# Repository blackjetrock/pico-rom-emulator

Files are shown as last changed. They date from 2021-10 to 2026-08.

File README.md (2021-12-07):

# pico-rom-emulator
ROM Emulator using Pico

This is a ROM emulator using a Raspberry Pi Pico to do the emulation in firmware.
The emulator is a small program that presents data on 8 data lines depending on the state of 16 address lines.
As the emulation is done in firmware there is a limit to the speed of ROm that can be emulated.
This has been teste on a 900kHz 6303 system (Psion Organiser) and also a 2MHz 6502 system. It may be able to run faster
and with overclocking faster than the standard clock rate can handle. 
As emulation is in firmware you get an extra for free, namely an address tracing facility. It can be set to start on any address, all setup is done
using the code itself and the trace is accessed through a debugger, I use Eclipse.

The emulation currently runs on the second core of the RP2040, as I was having problems with the interrupts on core0 mucking up
the emulation, turning interrupts off was a problem as download didn't work well. Using core 1 seems to be a better solution. It may even be possible to 
run a USB serial monitor of some kind on core 0 while emulating. I haven't got round ot this yet.

There's a PCB in the repo too, which is a Pico and some level shifters to allow the emulator to run on a 5V system when the Pico is 3V3. The data direction
is under firmware control. I have been using the emulator configured with a hardware OE which menas the OE signal to the ROM goes to the CE of the level
shifters. Placing data on the bus is therefore under hardware control. The PCB can be configured in other ways but I've not tried that.

This is a work in progress, but I have used it to get traces for stuff I've been working on.

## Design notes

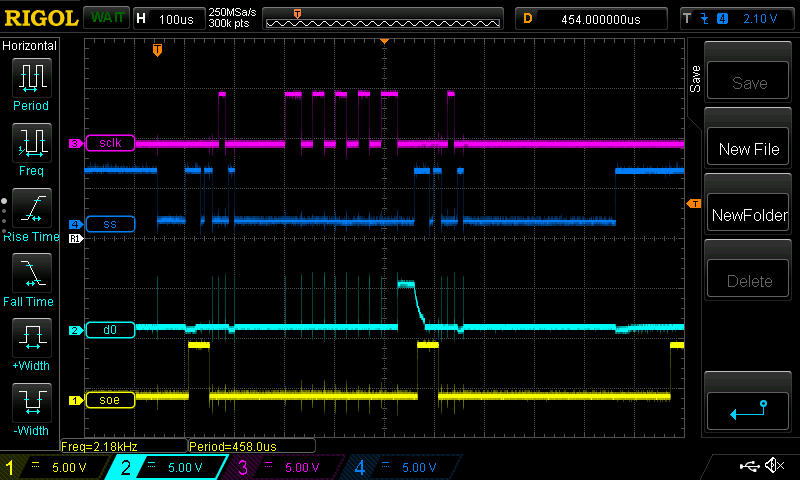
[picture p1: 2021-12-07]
code/pico-rom-em/scope_traces/rl_ep3.jpg

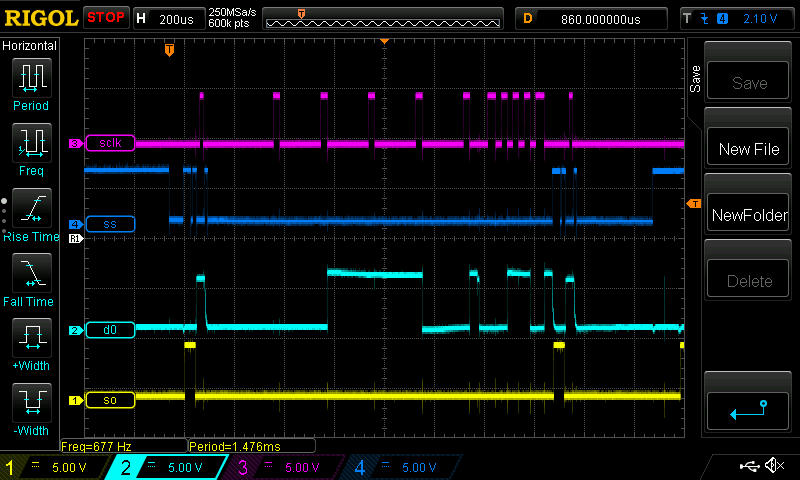
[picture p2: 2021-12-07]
code/scope_traces/rra2.jpg

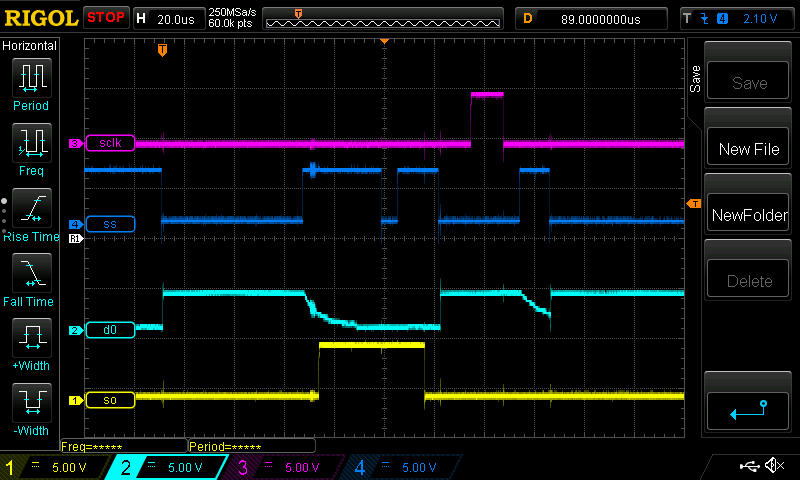
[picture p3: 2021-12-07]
code/scope_traces/g1.jpg

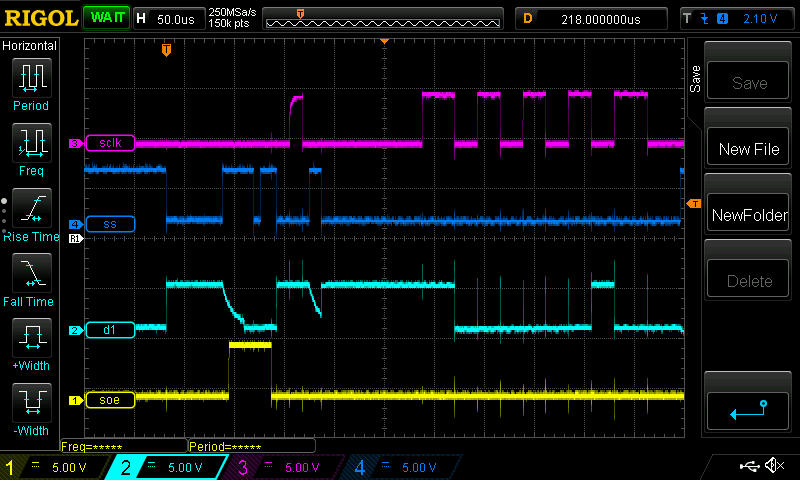
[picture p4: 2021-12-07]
code/scope_traces/rl_ep_d1_2.jpg

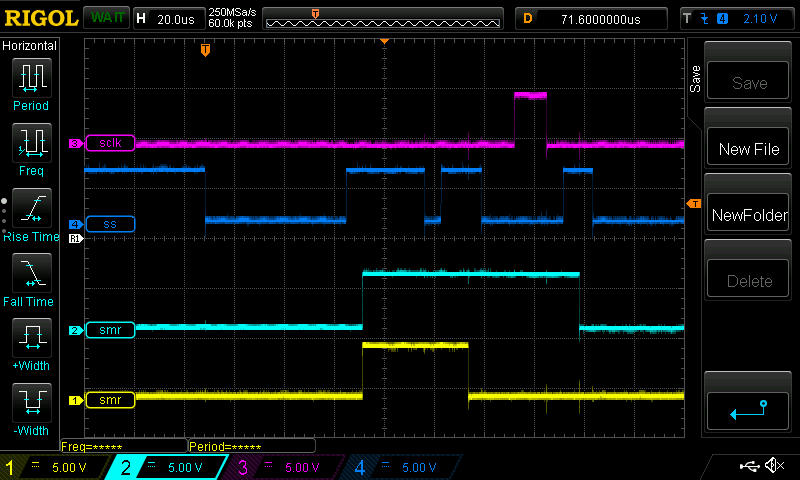
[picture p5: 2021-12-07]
code/pico-rom-em/scope_traces/NewFile10.jpg

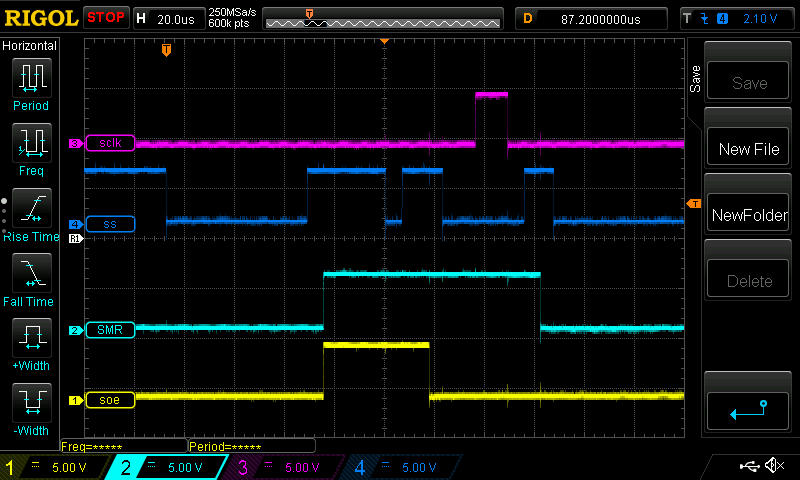
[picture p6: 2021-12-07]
code/scope_traces/RAMPAK2.jpg

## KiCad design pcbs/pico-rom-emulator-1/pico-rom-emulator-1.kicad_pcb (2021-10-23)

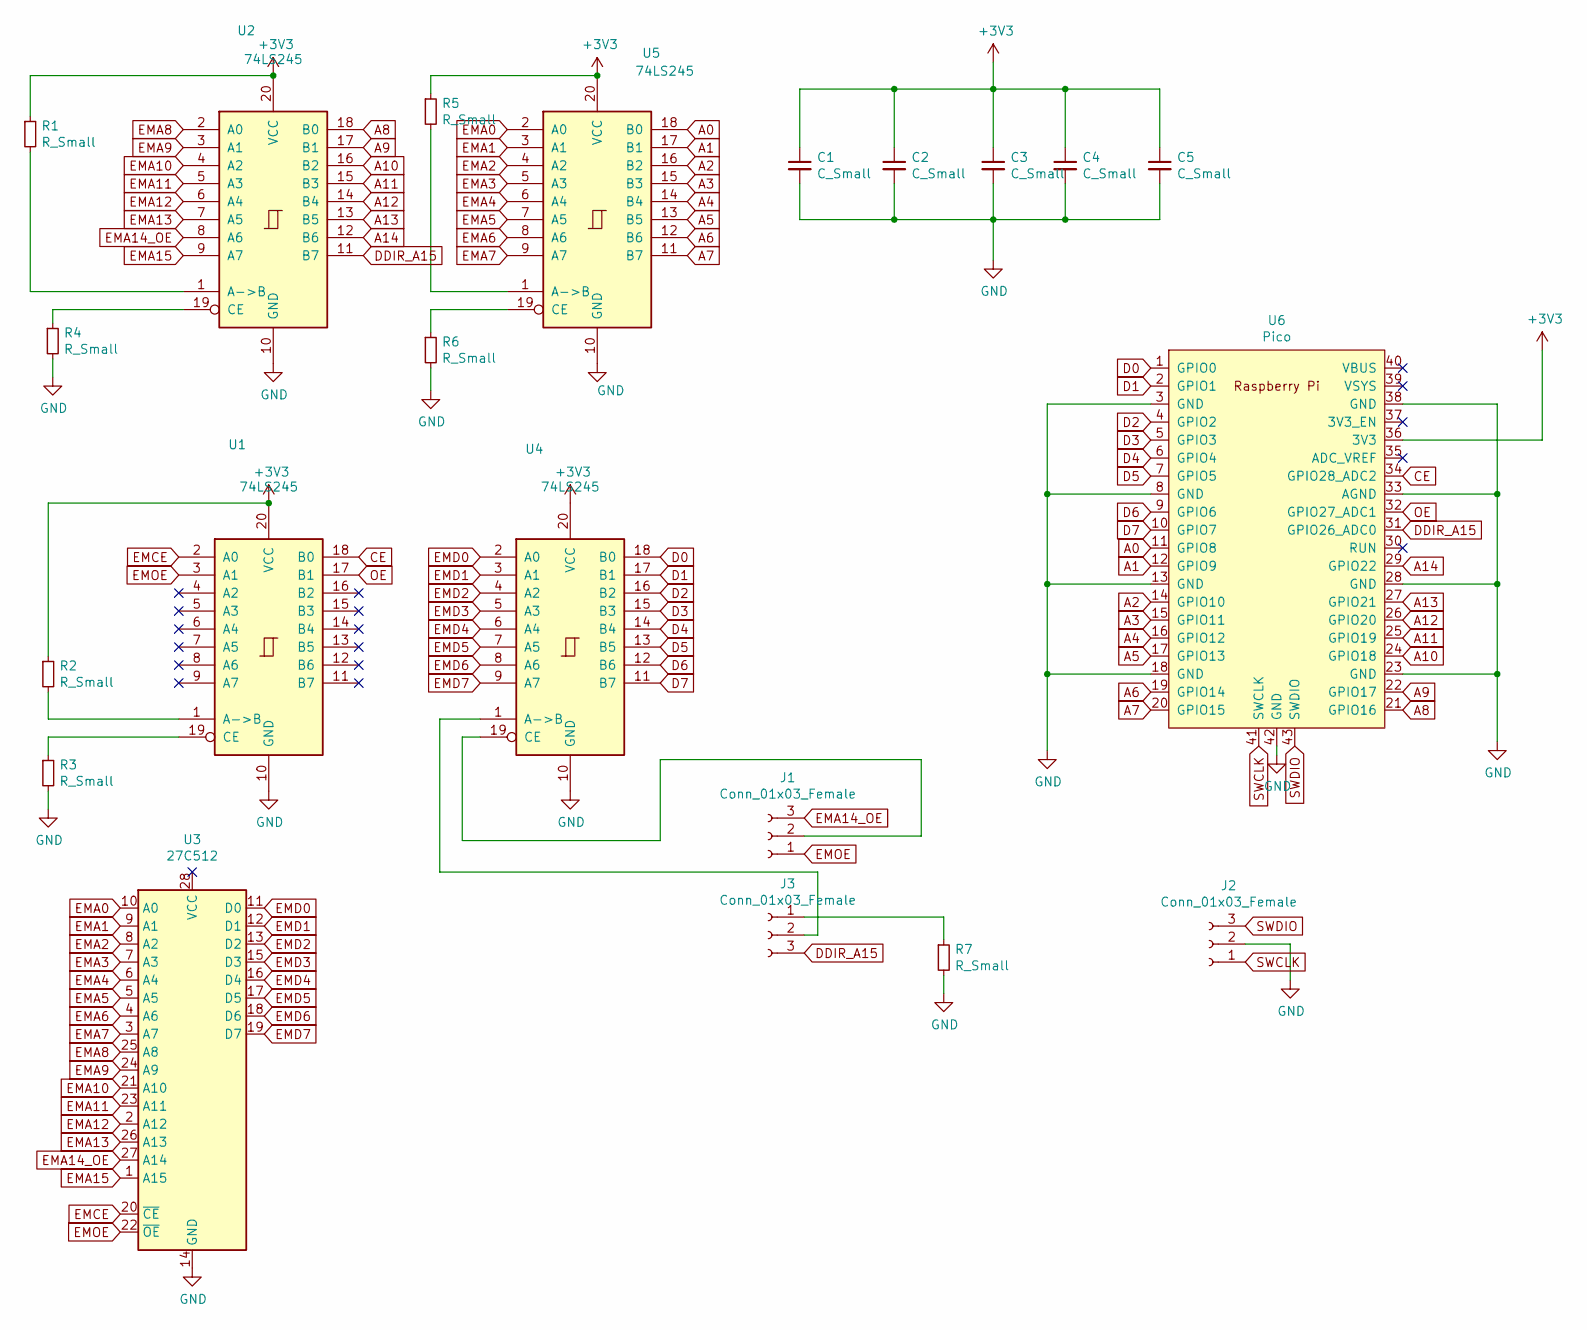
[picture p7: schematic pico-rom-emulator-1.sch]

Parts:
C1, C2, C3, C4, C5: C_Small; C_0805_2012Metric_Pad1.15x1.40mm_HandSolder
J1, J2, J3: Conn_01x03_Female; PinHeader_1x03_P2.54mm_Vertical
R1, R2, R3, R4, R5, R6, R7: R_Small; R_0805_2012Metric_Pad1.15x1.40mm_HandSolder
U1, U2, U4, U5: 74LS245; SOIC-20W_7.5x12.8mm_P1.27mm
U3: 27C512; DIP-28_W15.24mm
U6: Pico; RPi_Pico_SMD_TH

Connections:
+3V3: C1.1, C2.1, C3.1, C4.1, C5.1, R1.1, R2.1, R5.1, U1.20 (VCC), U2.20 (VCC), U4.20 (VCC), U5.20 (VCC), U6.36 (3V3)
A0: U5.18 (B0), U6.11 (GPIO8)
A1: U5.17 (B1), U6.12 (GPIO9)
A2: U5.16 (B2), U6.14 (GPIO10)
A3: U5.15 (B3), U6.15 (GPIO11)
A4: U5.14 (B4), U6.16 (GPIO12)
A5: U5.13 (B5), U6.17 (GPIO13)
A6: U5.12 (B6), U6.19 (GPIO14)
A7: U5.11 (B7), U6.20 (GPIO15)
A8: U2.18 (B0), U6.21 (GPIO16)
A9: U2.17 (B1), U6.22 (GPIO17)
A10: U2.16 (B2), U6.24 (GPIO18)
A11: U2.15 (B3), U6.25 (GPIO19)
A12: U2.14 (B4), U6.26 (GPIO20)
A13: U2.13 (B5), U6.27 (GPIO21)
A14: U2.12 (B6), U6.29 (GPIO22)
CE: U1.18 (B0), U6.34 (GPIO28_ADC2)
D0: U4.18 (B0), U6.1 (GPIO0)
D1: U4.17 (B1), U6.2 (GPIO1)
D2: U4.16 (B2), U6.4 (GPIO2)
D3: U4.15 (B3), U6.5 (GPIO3)
D4: U4.14 (B4), U6.6 (GPIO4)
D5: U4.13 (B5), U6.7 (GPIO5)
D6: U4.12 (B6), U6.9 (GPIO6)
D7: U4.11 (B7), U6.10 (GPIO7)
DDIR_A15: J3.3, U2.11 (B7), U6.31 (GPIO26_ADC0)
EMA0: U3.10 (A0), U5.2 (A0)
EMA1: U3.9 (A1), U5.3 (A1)
EMA2: U3.8 (A2), U5.4 (A2)
EMA3: U3.7 (A3), U5.5 (A3)
EMA4: U3.6 (A4), U5.6 (A4)
EMA5: U3.5 (A5), U5.7 (A5)
EMA6: U3.4 (A6), U5.8 (A6)
EMA7: U3.3 (A7), U5.9 (A7)
EMA8: U2.2 (A0), U3.25 (A8)
EMA9: U2.3 (A1), U3.24 (A9)
EMA10: U2.4 (A2), U3.21 (A10)
EMA11: U2.5 (A3), U3.23 (A11)
EMA12: U2.6 (A4), U3.2 (A12)
EMA13: U2.7 (A5), U3.26 (A13)
EMA14_OE: J1.3, U2.8 (A6), U3.27 (A14)
EMA15: U2.9 (A7), U3.1 (A15)
EMCE: U1.2 (A0), U3.20 (~CE)
EMD0: U3.11 (D0), U4.2 (A0)
EMD1: U3.12 (D1), U4.3 (A1)
EMD2: U3.13 (D2), U4.4 (A2)
EMD3: U3.15 (D3), U4.5 (A3)
EMD4: U3.16 (D4), U4.6 (A4)
EMD5: U3.17 (D5), U4.7 (A5)
EMD6: U3.18 (D6), U4.8 (A6)
EMD7: U3.19 (D7), U4.9 (A7)
EMOE: J1.1, U1.3 (A1), U3.22 (~OE)
GND: C1.2, C2.2, C3.2, C4.2, C5.2, J2.2, R3.2, R4.2, R6.2, R7.2, U1.10 (GND), U2.10 (GND), U3.14 (GND), U4.10 (GND), U5.10 (GND), U6.3 (GND), U6.8 (GND), U6.13 (GND), U6.18 (GND), U6.23 (GND), U6.28 (GND), U6.33 (AGND), U6.38 (GND), U6.42 (GND)
unnamed: J1.2, U4.19 (CE)
unnamed: J3.1, R7.1
unnamed: J3.2, U4.1 (A->B)
unnamed: R1.2, U2.1 (A->B)
unnamed: R2.2, U1.1 (A->B)
unnamed: R3.1, U1.19 (CE)
unnamed: R4.1, U2.19 (CE)
unnamed: R5.2, U5.1 (A->B)
unnamed: R6.1, U5.19 (CE)
OE: U1.17 (B1), U6.32 (GPIO27_ADC1)
SWCLK: J2.1, U6.41 (SWCLK)
SWDIO: J2.3, U6.43 (SWDIO)

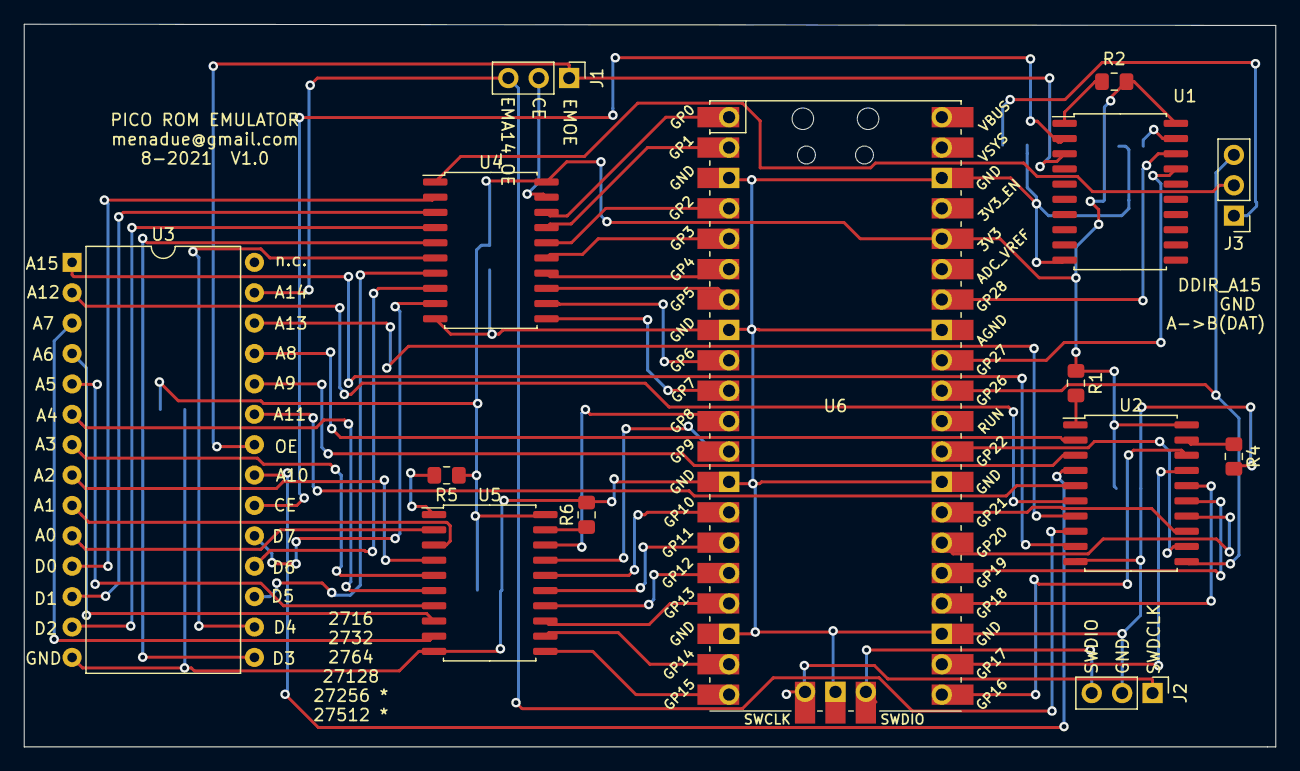
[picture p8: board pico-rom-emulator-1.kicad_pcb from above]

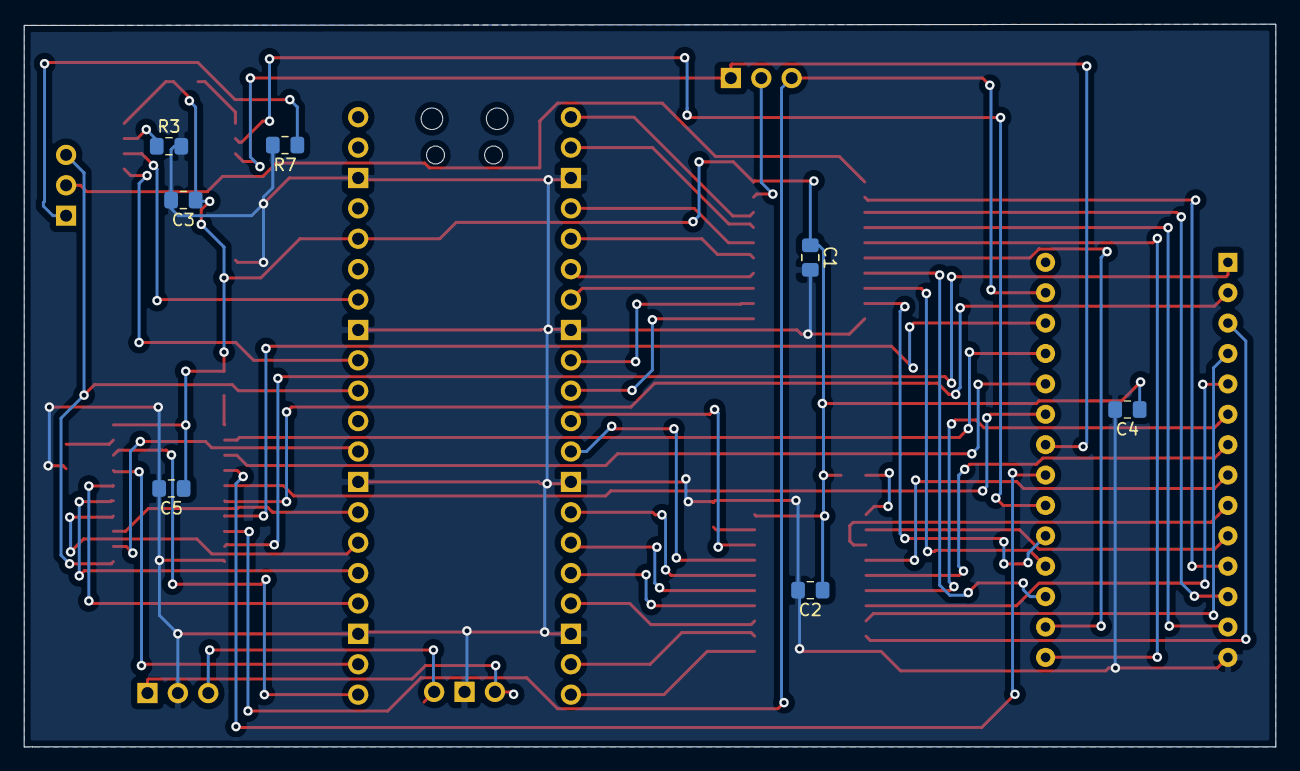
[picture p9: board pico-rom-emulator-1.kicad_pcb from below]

Board: 2 copper layers, 104.6 x 60.4 mm, 21 parts (7 on the bottom side), 65 nets.

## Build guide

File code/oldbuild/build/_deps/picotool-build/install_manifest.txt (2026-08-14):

/home/menadue/tree/github/pico-rom-emulator/code/build/_deps/picotool/picotool
/home/menadue/tree/github/pico-rom-emulator/code/build/_deps/picotool/picotoolTargets.cmake
/home/menadue/tree/github/pico-rom-emulator/code/build/_deps/picotool/picotoolTargets-release.cmake
/home/menadue/tree/github/pico-rom-emulator/code/build/_deps/picotool/picotoolConfig.cmake
/home/menadue/tree/github/pico-rom-emulator/code/build/_deps/picotool/picotoolConfigVersion.cmake

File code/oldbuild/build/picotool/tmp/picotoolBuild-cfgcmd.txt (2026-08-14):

cmd='/usr/bin/cmake;--no-warn-unused-cli;-DCMAKE_MAKE_PROGRAM:FILEPATH=/usr/bin/gmake;-DPICO_SDK_PATH:FILEPATH=/home/menadue/pico/pico-sdk;-DPICOTOOL_NO_LIBUSB=1;-DPICOTOOL_FLAT_INSTALL=1;-DCMAKE_INSTALL_PREFIX=/home/menadue/tree/github/pico-rom-emulator/code/build/_deps;-DCMAKE_RULE_MESSAGES=OFF;-DCMAKE_INSTALL_MESSAGE=NEVER;-GUnix Makefiles;-S;<SOURCE_DIR><SOURCE_SUBDIR>;-B;<BINARY_DIR>'

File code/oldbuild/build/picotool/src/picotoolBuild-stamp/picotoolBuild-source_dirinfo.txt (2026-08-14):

# This is a generated file and its contents are an internal implementation detail.
# The download step will be re-executed if anything in this file changes.
# No other meaning or use of this file is supported.

method=source_dir
command=
source_dir=/home/menadue/tree/github/pico-rom-emulator/code/build/_deps/picotool-src
work_dir=

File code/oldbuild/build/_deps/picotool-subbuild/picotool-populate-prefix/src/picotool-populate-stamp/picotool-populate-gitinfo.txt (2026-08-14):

# This is a generated file and its contents are an internal implementation detail.
# The download step will be re-executed if anything in this file changes.
# No other meaning or use of this file is supported.

method=git
command=/usr/bin/cmake;-DCMAKE_MESSAGE_LOG_LEVEL=VERBOSE;-P;/home/menadue/tree/github/pico-rom-emulator/code/build/_deps/picotool-subbuild/picotool-populate-prefix/tmp/picotool-populate-gitclone.cmake
source_dir=/home/menadue/tree/github/pico-rom-emulator/code/build/_deps/picotool-src
work_dir=/home/menadue/tree/github/pico-rom-emulator/code/build/_deps
repository=https://github.com/raspberrypi/picotool.git
remote=origin
init_submodules=TRUE
recurse_submodules=--recursive
submodules=
CMP0097=NEW

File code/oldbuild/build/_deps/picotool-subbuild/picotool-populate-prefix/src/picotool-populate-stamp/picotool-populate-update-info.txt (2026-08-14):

# This is a generated file and its contents are an internal implementation detail.
# The patch step will be re-executed if anything in this file changes.
# No other meaning or use of this file is supported.

command (connected)=/usr/bin/cmake;-Dcan_fetch=YES;-DCMAKE_MESSAGE_LOG_LEVEL=VERBOSE;-P;/home/menadue/tree/github/pico-rom-emulator/code/build/_deps/picotool-subbuild/picotool-populate-prefix/tmp/picotool-populate-gitupdate.cmake
command (disconnected)=/usr/bin/cmake;-Dcan_fetch=NO;-DCMAKE_MESSAGE_LOG_LEVEL=VERBOSE;-P;/home/menadue/tree/github/pico-rom-emulator/code/build/_deps/picotool-subbuild/picotool-populate-prefix/tmp/picotool-populate-gitupdate.cmake
work_dir=/home/menadue/tree/github/pico-rom-emulator/code/build/_deps/picotool-src

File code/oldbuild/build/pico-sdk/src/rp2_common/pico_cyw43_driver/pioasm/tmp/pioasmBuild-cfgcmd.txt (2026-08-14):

cmd='/usr/bin/cmake;--no-warn-unused-cli;-DCMAKE_MAKE_PROGRAM:FILEPATH=/usr/bin/gmake;-DPIOASM_FLAT_INSTALL=1;-DCMAKE_INSTALL_PREFIX=/home/menadue/tree/github/pico-rom-emulator/code/build/pioasm-install;-DCMAKE_RULE_MESSAGES=OFF;-DCMAKE_INSTALL_MESSAGE=NEVER;-GUnix Makefiles;-C<TMP_DIR>/pioasmBuild-cache-$<CONFIG>.cmake;-S;<SOURCE_DIR><SOURCE_SUBDIR>;-B;<BINARY_DIR>'

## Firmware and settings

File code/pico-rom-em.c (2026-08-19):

////////////////////////////////////////////////////////////////////////////////
//
// Pico ROM Emulator
//
////////////////////////////////////////////////////////////////////////////////


#include <ctype.h>
#include <stdio.h>
#include <string.h>
#include <stdlib.h>
#include "pico/stdlib.h"
//#include "hardware/i2c.h"
#include "hardware/pio.h"
#include "hardware/clocks.h"
#include "pico/multicore.h"
#include "pico/bootrom.h"

#if 0
#include "f_util.h"

#include "ff.h"
#include "ff_stdio.h"
#include "hw_config.h"
#include "my_debug.h"


#include "rtc.h"
#endif
#if 0
#include "sd_card.h"
#endif

typedef uint8_t BYTE;

// Use this if breakpoints don't work
#define DEBUG_STOP {volatile int x = 1; while(x) {} }

////////////////////////////////////////////////////////////////////////////////

void prompt(void);
void serial_help(void);

////////////////////////////////////////////////////////////////////////////////
//
// Tracing of processor accesses
//

#define TRACE_ON 0

// How many trace entries are displayed in a column
#define TRACE_B   32

// How many addresses are traced
#define TRACE_N   TRACE_B*4

volatile int trace_i = 0;
volatile int trace_running = 0;

volatile uint16_t trace_addr[TRACE_N];
volatile uint8_t trace_value[TRACE_N];
volatile char trace_type[TRACE_N];

////////////////////////////////////////////////////////////////////////////////


int parameter = 0;
int keypress = 0;

#define TEXT_PARAMETER_LEN 40
char text_parameter[TEXT_PARAMETER_LEN+1] = "";

//-----------------------------------------------------------------------------
//
// ROM Emulator Flags

// OE pin used to switch data direction
// If 0 then DDIR_A15 used, under processor conrol

#define USE_OE_FOR_DATA_DIRECTION 1

// The address lines we are looking at

// Do we run emulation on second core?
#define EMULATE_ON_CORE1   1

#define ROM_SIZE  2*1024
#define ADDRESS_MASK (ROM_SIZE - 1)


// Map from memory space to ROM address space
#define MAP_ROM(X) (X & ADDRESS_MASK)

volatile uint8_t rom_data[ROM_SIZE] =
  {
   // ASSEMBLER_EMBEDDED_CODE_START
0x4c,0x51,0xf9,0x4c,0xb2,0xf9,0x4c,0x9b,0xf9,0x4c,0x7d,0xfe,0xa9,0x0d,0x4c,0x79,
0xfe,0x4c,0xe9,0xfa,0x4c,0x0c,0xfb,0x4c,0x28,0xff,0x4c,0x0b,0xff,0x4c,0xfa,0xfd,
0xa2,0xff,0x9a,0x4c,0x37,0xfc,0x4c,0x16,0xfb,0x4c,0x23,0xfb,0x4c,0xdd,0xfe,0xf8,
0xfc,0x4c,0xc3,0xfe,0x4c,0x64,0xff,0xe0,0x03,0x01,0x00,0x00,0x00,0x40,0x24,0x00,
0x10,0x0a,0xa2,0x4f,0xb5,0x10,0x9d,0x00,0x01,0xca,0x10,0xf8,0xa9,0x00,0x85,0x00,
0xa9,0x8b,0x8d,0xd2,0xbf,0xa9,0xff,0x8d,0xd3,0xbf,0xa9,0x8b,0xcd,0xd2,0xbf,0xd0,
0x15,0xa9,0x93,0x8d,0xd3,0xbf,0xad,0xd1,0xbf,0x29,0x60,0xd0,0x09,0xa9,0x89,0x8d,
0xd2,0xbf,0xa9,0x21,0x85,0x00,0xa2,0xff,0x9a,0x4c,0x03,0xfc,0x85,0x02,0x8a,0x48,
0x98,0x48,0xad,0x2f,0xf8,0x48,0xad,0x30,0xf8,0x48,0xa6,0x02,0xa4,0x00,0x98,0x29,
0x04,0xd0,0x0a,0xe0,0x11,0xd0,0x18,0x98,0x09,0x04,0x85,0x00,0x60,0x98,0x29,0xfb,
0x85,0x00,0xe0,0x06,0xb0,0x09,0xbd,0x05,0xf9,0x48,0xbd,0x0b,0xf9,0x48,0x60,0xa5,
0x00,0x0a,0x0a,0xb0,0x0a,0x48,0x8a,0xc9,0x0a,0xf0,0x03,0x20,0x7d,0xfe,0x68,0xa6,
0x02,0xe0,0x7f,0xd0,0x04,0xa2,0x2f,0x86,0x02,0x0a,0x90,0x0d,0x48,0xe0,0x0d,0xd0,
0x04,0x29,0x10,0xd0,0x03,0x20,0x9b,0xf9,0x68,0x0a,0x90,0x0f,0x48,0xa6,0x02,0xe0,
0x0d,0xd0,0x04,0x29,0x20,0xf0,0x03,0x20,0xb2,0xf9,0x68,0x0a,0x90,0x03,0x20,0x02,
0xf9,0xa6,0x02,0xe0,0x0d,0xd0,0x05,0xa9,0x0a,0x20,0x7c,0xf8,0x60,0x68,0xa8,0x68,
0xaa,0x60,0x6c,0x11,0x00,0xf9,0xf9,0xf9,0xf9,0xf9,0xf9,0x8d,0x86,0x40,0x39,0x73,
0x7a,0x8d,0xf0,0xbf,0xc9,0x10,0xd0,0x06,0x20,0x34,0xf9,0x4c,0x2f,0xf9,0xc9,0x13,
0xd0,0x06,0x20,0x6e,0xf9,0x4c,0x2f,0xf9,0xc9,0x16,0xd0,0x07,0x20,0x81,0xf9,0xa9,
0x00,0x85,0x01,0x60,0xa5,0x00,0x29,0x10,0xf0,0x07,0xa5,0x00,0x29,0xef,0x85,0x00,
0x60,0xa9,0x00,0x8d,0xe3,0xbf,0xcd,0xe3,0xbf,0xd0,0x22,0xa5,0x00,0x09,0x10,0x85,
0x00,0xa9,0xff,0x8d,0xe3,0xbf,0xa9,0xfe,0x8d,0xe0,0xbf,0xa9,0x09,0x8d,0xe2,0xbf,
0xa9,0x0f,0x8d,0xe1,0xbf,0x20,0xdb,0xf9,0xa9,0xff,0x8d,0xe0,0xbf,0x60,0xa5,0x00,
0x29,0x40,0xf0,0x07,0xa5,0x00,0x29,0xbf,0x85,0x00,0x60,0xa5,0x00,0x09,0x40,0xd0,
0xf7,0xa5,0x00,0x29,0x20,0xf0,0x07,0xa5,0x00,0x29,0xdf,0x85,0x00,0x60,0xad,0xd2,
0xbf,0xc9,0xff,0xf0,0xf2,0xa5,0x00,0x09,0x20,0xd0,0xf0,0xa2,0x00,0xad,0xd1,0xbf,
0x29,0x10,0xd0,0x08,0x88,0xd0,0xfd,0xca,0xd0,0xf3,0xf0,0x3e,0xa5,0x02,0x8d,0xd0,
0xbf,0x60,0xad,0xe0,0xbf,0x29,0x04,0xf0,0x31,0xa2,0xff,0x98,0xa0,0x0f,0x88,0x10,
0xfd,0xa8,0x88,0xd0,0x03,0xca,0xf0,0x22,0xad,0xe0,0xbf,0x29,0x02,0xd0,0xec,0xad,
0xed,0xbf,0x29,0x02,0xf0,0xe5,0xa5,0x02,0x8d,0xe1,0xbf,0xa9,0x0d,0x8d,0xec,0xbf,
0xe9,0x01,0xd0,0xfc,0xa9,0x0f,0x8d,0xec,0xbf,0x60,0xa5,0x00,0x29,0x8f,0x85,0x00,
0xa2,0x0c,0xbd,0xfc,0xf9,0x20,0x79,0xfe,0xca,0x10,0xf7,0x60,0x0d,0x52,0x4f,0x52,
0x52,0x45,0x20,0x54,0x4e,0x49,0x52,0x50,0x0d,0x88,0x10,0x16,0xa5,0x0a,0x38,0xe9,
0x20,0x85,0x0a,0xa5,0x0b,0xe9,0x00,0x85,0x0b,0xa0,0x1f,0xc9,0x01,0xd0,0x03,0x20,
0x23,0xfa,0x60,0xa0,0x00,0xa9,0x20,0x99,0x00,0x02,0x99,0x00,0x03,0xc8,0xd0,0xf7,
0x98,0x85,0x0a,0xa9,0x02,0x85,0x0b,0x60,0xa2,0x00,0xbd,0x20,0x02,0x9d,0x00,0x02,
0xe8,0xd0,0xf7,0xbd,0x20,0x03,0x9d,0x00,0x03,0xe8,0xe0,0xe0,0xd0,0xf5,0x86,0x0a,
0xa9,0x03,0x85,0x0b,0xa9,0x20,0xa8,0x88,0x91,0x0a,0xd0,0xfb,0x60,0xa0,0x00,0xbd,
0x6d,0xfa,0xd0,0x01,0x60,0xd1,0x0a,0xd0,0xfb,0xe8,0xc8,0xd0,0xf2,0x42,0x41,0x53,
0x00,0x57,0x41,0x52,0x00,0xa2,0x00,0x20,0x5d,0xfa,0xd0,0x08,0x06,0x00,0x38,0x66,
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

// ASSEMBLER_EMBEDDED_CODE_END
  };

//------------------------------------------------------------------------------

const int D0_PIN = 0;
const int D1_PIN = 1;
const int D2_PIN = 2;
const int D3_PIN = 3;
const int D4_PIN = 4;
const int D5_PIN = 5;
const int D6_PIN = 6;
const int D7_PIN = 7;

//
// The address lines (always inputs)
//
const int  A0_PIN  =  8;
const int  A1_PIN  =  9;
const int  A2_PIN  = 10;
const int  A3_PIN  = 11;
const int  A4_PIN  = 12;
const int  A5_PIN  = 13;
const int  A6_PIN  = 14;
const int  A7_PIN  = 15;
const int  A8_PIN  = 16;
const int  A9_PIN  = 17;
const int  A10_PIN = 18;
const int  A11_PIN = 19;
const int  A12_PIN = 20;
const int  A13_PIN = 21;
const int  A14_PIN = 22;
const int  DDIR_A15_PIN = 26;

const int OE_PIN = 27;
const int CE_PIN = 28;

// Arrays for setting GPIOs up
#define NUM_ADDR 16
#define NUM_DATA 8

#define CE_OE_MASK ((1 << CE_PIN) | (1 << OE_PIN))

const int address_pins[NUM_ADDR] =
  {
   A0_PIN,
   A1_PIN,
   A2_PIN,
   A3_PIN,
   A4_PIN,
   A5_PIN,
   A6_PIN,
   A7_PIN,
   A8_PIN,
   A9_PIN,
   A10_PIN,
   A11_PIN,
   A12_PIN,
   A13_PIN,
   A14_PIN,
   DDIR_A15_PIN,
  };

const int data_pins[NUM_DATA] =
  {
   D0_PIN,
   D1_PIN,
   D2_PIN,
   D3_PIN,
   D4_PIN,
   D5_PIN,
   D6_PIN,
   D7_PIN,
  };

////////////////////////////////////////////////////////////////////////////////

//-----------------------------------------------------------------------------
//
// Put a value on the data bus

inline void set_data(BYTE data)
{
  int states;
  int dat = data & 0xff;
  
  // Direct register access to make things faster
  sio_hw->gpio_set = (  dat  << 0);
  sio_hw->gpio_clr = ((dat ^ 0xFF) << 0);
}



////////////////////////////////////////////////////////////////////////////////
//
// Set things up then sit in a loop waiting for the emulated devcie to
// be selected
//
////////////////////////////////////////////////////////////////////////////////

#define MAX_ADDR_TRACE 1024*64
int trace_on = 0;
volatile int addr_trace_index = 0;
volatile uint16_t addr_trace[MAX_ADDR_TRACE];
volatile unsigned int number_ce_assert = 0;

void rom_emulate(void)
{

  irq_set_mask_enabled( 0xFFFFFFFF, false );

  while(1)
    {
      uint32_t gpio_states;
      BYTE db;
      unsigned int addr;
      unsigned int last_addr;

      // Get off bus
      gpio_put(DDIR_A15_PIN, 1);
      
      // read GPIOs
      gpio_states = sio_hw->gpio_in;
      
      // We look for CE and OE being low
      if( (gpio_states & CE_OE_MASK) != 0 )
      	{
          // CE high, we are not selected

        }
      else
      	{
          // CE and OE low, we are selected
          // Drive bus
          gpio_put(DDIR_A15_PIN, 0);
                
          // ROM emulation so always a read of us
          // get address
          addr = (gpio_states >> 8) & ADDRESS_MASK;
	  
          // Get data and present it on bus
          set_data(rom_data[addr]);

          //          printf("\nA");
          //set_data(0xF8);
	  
#if TRACE_ON
          if( trace_running )
            {
              trace_addr[trace_i] = addr;
              trace_value[trace_i] = rom_data[addr];
              trace_type[trace_i++] = 'R';
              if( trace_i == TRACE_N )
                {
                  trace_running = 0;
                }
            }
#endif

          last_addr = addr;
          
          number_ce_assert++;
#if 1
          // Wait for CE or OE to be de-asserted
          while(1)
            {
              gpio_states = sio_hw->gpio_in;
	      
              // We look for CE and OE to be non zero
              if( (gpio_states & CE_OE_MASK) != 0 )
                {
                  // get off bus quickly
                  gpio_put(DDIR_A15_PIN, 1);
                  
                  //                  printf("\nD");
                  // CE or OE high, we are not selected
#if TRACE_ON
                  if( trace_running && (last_addr != addr)  )
                    {
                      trace_addr[trace_i] = addr;
                      trace_value[trace_i] = rom_data[addr];
                      trace_type[trace_i++] = 'X';
                      if( trace_i == TRACE_N )
                        {
                          trace_running = 0;
                        }
                    }
#endif
                  break;
                }

              // CE and OE low, we are selected
              // ROM emulation so always a read of us
              // get address
              addr = (gpio_states >> 8) & ADDRESS_MASK;
              
              // Get data and present it on bus
              set_data(rom_data[addr]);
              
#if TRACE_ON
              if( trace_running && (last_addr != addr)  )
                {
                  trace_addr[trace_i] = addr;
                  trace_value[trace_i] = rom_data[addr];
                  trace_type[trace_i++] = 'L';
                  if( trace_i == TRACE_N )
                    {
                      trace_running = 0;
                    }
                }
#endif
              last_addr = addr;
            }
#endif
        }
    }
}

////////////////////////////////////////////////////////////////////////////////
//
// trace what the processor is doing

void cli_trace_addresses(void)
{
  trace_i = 0;
  trace_running = 1;
}

void cli_dump_trace(void)
{
  printf("\nTrace\n");
  printf("\nTrace index;%d Trace running:%d\n", trace_i, trace_running);
  
  for(int i = 0; i<TRACE_B; i++)
    {
      printf("\n");
      for(int b = 0; b< TRACE_N/TRACE_B; b++)
        {
          int bi = i+TRACE_B*b;
          printf("%02X: %04X %c %02X   ", bi, trace_addr[bi], trace_type[bi], trace_value[bi]);
        }
    }
  printf("\n");
}


////////////////////////////////////////////////////////////////////////////////

void cli_boot_mass(void)
{
  reset_usb_boot(0,0);
}

void cli_information(void)
{
  printf("\nInformation");
}

////////////////////////////////////////////////////////////////////////////////
//
//
// We allow digits to enter a new value for the parameter

void cli_enter_parameter()
{
  int  key;
  int done = 0;

  printf("\nEnter parameter: (ESC or <RETURN> to exit)");
  
  parameter = 0;
  
  while(!done)
    {
      if( ((key = getchar_timeout_us(1000)) != PICO_ERROR_TIMEOUT))
	{
#if PAR_TYPE_DEC
	  switch(key)
	    {
	    case '0':
	    case '1':
	    case '2':
	    case '3':
	    case '4':
	    case '5':
	    case '6':
	    case '7':
	    case '8':
	    case '9':
	      parameter *= 10;
	      parameter += (key - '0');
	      prompt();
	      break;

	    case 27:
	    case 13:
	    case 10:
	      done = 1;
	      break;
	      
	    default:
	      break;
	    }
#else
	  switch(key)
	    {
	    case '0':
	    case '1':
	    case '2':
	    case '3':
	    case '4':
	    case '5':
	    case '6':
	    case '7':
	    case '8':
	    case '9':
	      parameter *= 16;
	      parameter += (key - '0');
	      prompt();
	      break;
              
	    case 'a':
	    case 'b':
	    case 'c':
	    case 'd':
	    case 'e':
	    case 'f':
	      parameter *= 16;
	      parameter += (key - 'a'+10);
	      prompt();
              break;
              
	    case 27:
	    case 13:
	    case 10:
	      done = 1;
	      break;
	      
	    default:
	      break;
	    }
#endif
	}
      else
	{
	  // I have found that I need to send something if the serial USB times out
	  // otherwise I get lockups on the serial communications.
	  // So, if we get a timeout we send a space and backspace it. And
	  // flush the stdio, but that didn't fix the problem but seems like a good idea.
	  stdio_flush();
	  //printf(" \b");
	}
    }
}

////////////////////////////////////////////////////////////////////////////////

#define BYTE_WIDTH 16

void cli_dump_ram(void)
{
  char ascii[BYTE_WIDTH*3+5];
  char ascii_byte[5];

  // Bound the address to 64K

  parameter %= 64*1024;
  
  // Display memory from address
  printf("\n");

  ascii[0] = '\0';
  
  for(unsigned int z = parameter; z<parameter+512; z++)
    {
      int byte = 0;
      
      if( (z % BYTE_WIDTH) == 0)
	{
	  printf("  %s", ascii);
	  ascii[0] = '\0';
	  printf("\n%08X: ", z);
	}

      byte = rom_data[z];

      printf(" %02X", byte);
      
      if( isprint(byte) )
	{
	  sprintf(ascii_byte, "%c", byte);
	}
      else
	{
	  sprintf(ascii_byte, ".");
	}
      
      strcat(ascii, ascii_byte);
    }
  
  printf("\n");

  parameter += 512;
}

//------------------------------------------------------------------------------

void cli_dump_ram2(void)
{
  for(int a=parameter; a<parameter+256; a++)
    {
      if( (a % 16) == 0 )
        {
          printf("\n%04X: ", a);
        }
      else
        {
          if( (a % 8) == 0 )
            {
              printf(" ");
            }
        }
      
      printf(" %02X", rom_data[a]);
    }

  printf("\n");
  
}
////////////////////////////////////////////////////////////////////////////////

void prompt(void)
{
  printf("\n\n(Text Parameter:'%s'", text_parameter);
#if PAR_TYPE_DEC
  printf("\n(Parameter %d >", parameter);
#else
  printf("\n(Parameter 0x%04X >", parameter);
#endif
}

////////////////////////////////////////////////////////////////////////////////

void cli_digit(void)
{
  printf("\n%d", keypress);
}

////////////////////////////////////////////////////////////////////////////////

// Serial loop command structure

typedef void (*SERIAL_FPTR)(void);

typedef struct
{
  char key;
  char *desc;
  SERIAL_FPTR fn;
} SERIAL_COMMAND;

SERIAL_COMMAND serial_cmds[] =
  {
    {
      '?',
      "Serial command help",
      serial_help,
    },
    {
      '!',
      "Boot to mass storage",
      cli_boot_mass,
    },
    {
      'i',
      "Information",
      cli_information,
    },
    {
      't',
      "Trace",
      cli_trace_addresses,
    },
    {
      'u',
      "Dump trace",
      cli_dump_trace,
    },
    {
      'a',
      "Dump RAM",
      cli_dump_ram,
    },
    {
      'z',
      "Enter parameter value",
      cli_enter_parameter,
    },
    {
      '0',
      "*Digit",
      cli_digit,
    },
    {
      '1',
      "*Digit",
      cli_digit,
    },
    {
      '2',
      "*Digit",
      cli_digit,
    },
    {
      '3',
      "*Digit",
      cli_digit,
    },
    {
      '4',
      "*Digit",
      cli_digit,
    },
    {
      '5',
      "*Digit",
      cli_digit,
    },
    {
      '6',
      "*Digit",
      cli_digit,
    },
    {
      '7',
      "*Digit",
      cli_digit,
    },
    {
      '8',
      "*Digit",
      cli_digit,
    },
    {
      '9',
      "*Digit",
      cli_digit,
    },
  };


////////////////////////////////////////////////////////////////////////////////
//
// Serial CLI Handling
//
////////////////////////////////////////////////////////////////////////////////

int pcount = 0;
int periodic_read = 0;

void serial_loop()
{
  int  key;
  
  if( ((key = getchar_timeout_us(1000)) != PICO_ERROR_TIMEOUT))
    {
      for(int i=0; i<sizeof(serial_cmds)/sizeof(SERIAL_COMMAND);i++)
	{
	  if( serial_cmds[i].key == key )
	    {
#if DEBUG_SERIAL
	      printf("\nKey:%d (0x%02X)", key, key);
#endif
	      keypress = key;
	      (*serial_cmds[i].fn)();
	      prompt();
	      break;
	    }
	}
    }
}

void serial_help(void)
{
  printf("\n");
  
  for(int i=0; i<sizeof(serial_cmds)/sizeof(SERIAL_COMMAND);i++)
    {
      if( *(serial_cmds[i].desc) != '*' )
	{
	  printf("\n%c:   %s", serial_cmds[i].key, serial_cmds[i].desc);
	}
    }
  printf("\n0-9: Enter parameter digit");
}


int main()
{

  ////////////////////////////////////////////////////////////////////////////////
  //
  // Overclock as needed
  //
  ////////////////////////////////////////////////////////////////////////////////
  
  //#define OVERCLOCK 135000
  //#define OVERCLOCK 200000
#define OVERCLOCK 270000
  //#define OVERCLOCK 360000
  
#if OVERCLOCK > 270000
  /* Above this speed needs increased voltage */
  vreg_set_voltage(VREG_VOLTAGE_1_20);
  sleep_ms(1000);
#endif
  
  /* Overclock */
  set_sys_clock_khz( OVERCLOCK, 1 );

  //DEBUG_STOP;
  
  char line[80];

  stdio_init_all();

  printf("\nPico ROM Emulator\n");
  
#if TEST_STDIO
  {
  int count;
  while (true)
    {
      count++;
      
      if( (count % 1000000) == 0 )
	{
	  sprintf(line, "\nRP2040: %d", count);
	  printf(line);
	}
    }
  }
#endif

  printf("\nSetting GPIOs...");

  for (int i=0; i<NUM_ADDR; i++)
    {
      // Set up directions for the control lines
      gpio_init(address_pins[i]);
      gpio_set_dir(address_pins[i], GPIO_IN);
    }

  for (int i=0; i<NUM_DATA; i++)
    {
      // Set up directions for the control lines
      gpio_init(data_pins[i]);
      gpio_set_dir(data_pins[i], GPIO_OUT);
    }

  gpio_init(OE_PIN);
  gpio_set_dir(OE_PIN, GPIO_IN);
  gpio_init(CE_PIN);
  gpio_set_dir(CE_PIN, GPIO_IN);

  // DEBUG: Use DDIR_A15 as status line
  gpio_init(DDIR_A15_PIN);
  gpio_set_dir(DDIR_A15_PIN, GPIO_OUT);

  int ce = 0;

#if 0
  while(1)
    {
      ce = gpio_get(CE_PIN);
      gpio_put(DDIR_A15_PIN, ce);
    }
#endif

#if 0
  while(1)
    {
      uint32_t gpio_states;
      gpio_states = sio_hw->gpio_in;
      if( gpio_states & (1 << CE_PIN))
	{
	  gpio_put(DDIR_A15_PIN, 1);
	}
      else
	{
	  gpio_put(DDIR_A15_PIN, 0);
	}
    }
#endif

#if 0
  gpio_init(DDIR_A15_PIN);
  gpio_set_dir(DDIR_A15_PIN, GPIO_OUT);

  while(1)
    {
      printf("\nONE");
      gpio_put(DDIR_A15_PIN, 1);
      printf("\nZero");
      gpio_put(DDIR_A15_PIN, 0);
    }
#endif

  
  //set_data_outputs();
#if 0
#if !USE_OE_FOR_DATA_DIRECTION


  // LS_DIR is an output
  gpio_set_dir(LS_DIR_PIN, GPIO_OUT);
#else
  gpio_put(DDIR_A15_PIN, 0);
  gpio_set_dir(DDIR_A15_PIN, GPIO_OUT);
#endif
#endif
  

  // Use a polling loop for minimum latency
#if 0
  // Turn off timer interrupts
  irq_set_mask_enabled(0xf, false);
#endif
  
  // We set the CE of the level shifters to be driven by OE on the
  // host board, and the direction (A->B) to be set up by the Pico
  // The data direction can be left as output from the Pico as
  // the OE/CE line will drive on to the data bus when OE is asserted


#if 0
  while(1)
    {
      set_data(0xf8);
    }
#endif

#if EMULATE_ON_CORE1
  multicore_launch_core1(rom_emulate);

  printf("\n");
  printf("\n                                  ********************************************");
  printf("\n                                  *             Pico RPM Emulator             *");
  printf("\n                                  ********************************************");
  printf("\n");
  printf("\n");

  int count = 0;
  
  while(1)
  {
    count++;

    if( (count % 10000) == 0 )
      {
        //        printf("\n%d", count);
      }
    serial_loop();
  }


#else
  rom_emulate();
#endif
  
      //      gpio_put(DDIR_A15_PIN, 0);

}

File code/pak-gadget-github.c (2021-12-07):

#include <stdio.h>
#include "pico/stdlib.h"
//#include "hardware/i2c.h"
#include "hardware/pio.h"
#include "hardware/clocks.h"
#include "pico/multicore.h"

#include "f_util.h"
#include "ff.h"
#include "hw_config.h"
#include "my_debug.h"
#include "rtc.h"

// redefine pins to match our hardware
#define PICO_SD_CLK_PIN  5
#define PICO_SD_CMD_PIN  18
#define PICO_SD_DAT0_PIN 19
#define ENABLE_4_PIN 0
#include "sd_card.h"

#define SUPPORT_ID_BYTE  1
#define PAK_ID_BYTE      0x01
#define READ_ONLY        0
#define INIT_PAK_MEMORY  1
#define FF_FIRST_BYTES   0

#define DIRECT_GPIO  1

// Do we use a polling loop of interrupts?
#define USE_INTERRUPTS  0
#define USE_POLLING     1

#define MULTICORE_POLL   1

// The address into pak memory
#define PAK_ADDRESS (ss_address | ss_page)

const uint SDA_PIN    = 28;
const uint SCL_PIN    = 17;

#ifndef I2C_FUNCTIONS_H_
#define I2C_FUNCTIONS_H_

typedef unsigned char BYTE;

const int SLOT_SPGM_PIN = 2;
const int SLOT_SS_PIN   = 3;
const int SLOT_SCLK_PIN = 4;
const int SW3_PIN       = 5;
const int SLOT_SOE_PIN  = 6;
const int SLOT_SMR_PIN  = 7;

const int SLOT_SD0_PIN  = 8;
const int SLOT_SD1_PIN  = 9;
const int SLOT_SD2_PIN  = 10;
const int SLOT_SD3_PIN  = 11;
const int SLOT_SD4_PIN  = 12;
const int SLOT_SD5_PIN  = 13;
const int SLOT_SD6_PIN  = 14;
const int SLOT_SD7_PIN  = 15;

const int LS_DIR_PIN    = 27;

volatile int ss_count = 0;
volatile int soe_state = 1;
volatile int ss_address = 0;
volatile int ss_page = 0;


// Memory that emulates a pak
typedef unsigned char BYTE;

#define TRACE_LENGTH 8192
BYTE trace[TRACE_LENGTH];

int trace_i = 0;
//#define TRACE(XX) if(trace_i != (TRACE_LENGTH-1)) {trace[trace_i++] = XX; trace_i %= TRACE_LENGTH;}
#define TRACE(XX)

//#define WRITE_TRAP if( (PAK_ADDRESS + data) == 0)  while(1);

//#define WRITE_TRAP if( (ss_address + data + ss_page) == 0){  gpio_put(22,1);     gpio_put(22,0);}
#define WRITE_TRAP

#define PAK_MEMORY_SIZE  32768


#if !INIT_PAK_MEMORY
volatile BYTE pak_memory[PAK_MEMORY_SIZE];
#else

BYTE pak_memory[PAK_MEMORY_SIZE] =
  {
   
   0x78,0x04,0x56,0x00,0x03,0x02,0x35,0x46,0x06,0x4c,
   0x09,0x81,0x4d,0x41,0x49,0x4e,0x20,0x20,0x20,0x20,0x90,0x09,0x83,0x46,0x49,0x53,
   0x48,0x20,0x20,0x20,0x20,0x00,0x02,0x80,0x01,0x26,0x01,0x22,0x00,0x29,0x00,0xfc,
   0x00,0x00,0x13,0x02,0x59,0x25,0x00,0xff,0xe9,0x03,0x44,0x52,0x24,0x02,0xff,0xe6,
   0x02,0x46,0x24,0x02,0xff,0xdc,0x00,0x00,0x00,0x06,0xff,0xe5,0x02,0xff,0xdb,0x08,
   0x00,0x00,0x0f,0xff,0xdc,0x24,0x04,0x46,0x49,0x53,0x48,0x20,0x02,0x20,0x01,0x7d,
   0x06,0x45,0x58,0x49,0x53,0x54,0x24,0x81,0x02,0xff,0xdc,0x24,0x00,0x4a,0x7e,0x00,
   0x32,0x0d,0xff,0xd9,0x24,0x10,0x43,0x52,0x45,0x41,0x54,0x45,0x2d,0x46,0x49,0x4c,
   0x45,0x2c,0x51,0x55,0x49,0x54,0x98,0x7f,0x00,0xff,0xd9,0x022,0x00,0x01,0x2c,0x7e,
   0x00,0x10,0x20,0x00,0x7d,0x06,0x46,0x49,0x53,0x48,0x43,0x52,0x84,0x51,0x00,0x03,
   0x7b,0x20,0x00,0x7d,0x06,0x46,0x49,0x53,0x48,0x4f,0x50,0x84,0x20,0x00,0x7d,0x06,
   0x4d,0x41,0x44,0x55,0x44,0x47,0x84,0x0d,0xff,0xd7,0x24,0x20,0x41,0x44,0x44,0x2d,
   0x4e,0x45,0x57,0x2d,0x46,0x49,0x53,0x48,0x2c,0x53,0x45,0x41,0x52,0x43,0x48,0x2c,
   0x52,0x45,0x50,0x4f,0x52,0x54,0x2c,0x55,0x54,0x49,0x4c,0x53,0x98,0x7f,0x00,0xff,
   0xd7,0x22,0x00,0x01,0x2c,0x7e,0x00,0x14,0x20,0x00,0x7d,0x07,0x46,0x49,0x53,0x48,
   0x41,0x44,0x44,0x84,0x51,0xff,0xc2,0x51,0x00,0x55,0x00,0xff,0xd7,0x22,0x00,0x02,
   0x2c,0x7e,0x00,0x14,0x20,0x00,0x7d,0x07,0x46,0x49,0x53,0x48,0x53,0x45,0x45,0x84,
   0x51,0xff,0xa6,0x51,0x00,0x39,0x00,0xff,0xd7,0x22,0x00,0x03,0x2c,0x7e,0x00,0x14,
   0x20,0x00,0x7d,0x07,0x46,0x49,0x53,0x48,0x52,0x45,0x50,0x84,0x51,0xff,0x8a,0x51,
   0x00,0x1d,0x00,0xff,0xd7,0x22,0x00,0x04,0x2c,0x7e,0x00,0x12,0x20,0x00,0x7d,0x05,
   0x55,0x54,0x49,0x4c,0x53,0x84,0x51,0xff,0x70,0x51,0x00,0x03,0x7b,0x7b,0x00,0x00,
   0x09,0x83,0x46,0x49,0x53,0x48,0x41,0x44,0x44,0x20,0x00,0x02,0x80,0x06,0x11,0x06,
   0x0d,0x00,0x3a,0x05,0xee,0x00,0x00,0x00,0x00,0x00,0x00,0x12,0xff,0xf4,0x06,0xff,
   0xe6,0x04,0xff,0xe2,0x02,0xff,0xde,0x02,0xff,0xd8,0x04,0xff,0xc6,0x10,0x00,0x00,
   0x4e,0x24,0x0f,0x45,0x58,0x45,0x20,0x74,0x6f,0x20,0x63,0x6f,0x6e,0x74,0x69,0x6e,
   0x75,0x65,0x71,0x73,0x24,0x0d,0x43,0x4c,0x45,0x41,0x52,0x20,0x74,0x6f,0x20,0x71,
   0x75,0x69,0x74,0x71,0x73,0x0d,0xff,0xfc,0x91,0x7f,0x00,0xff,0xfc,0x22,0x00,0x0d,
   0x2b,0x7e,0x00,0x03,0x7b,0x4e,0x62,0x24,0x04,0x44,0x41,0x59,0x24,0x1f,0x00,0xb9,
   0x22,0x00,0x10,0xc0,0x81,0x0f,0xff,0xc7,0x24,0x04,0x44,0x41,0x59,0x24,0x1c,0x00,
   0x81,0x24,0x04,0x44,0x41,0x59,0x24,0x1f,0x00,0x6b,0x24,0x04,0x44,0x41,0x59,0x24,
   0x1c,0x00,0x02,0xff,0xc7,0x49,0x7e,0x00,0x85,0x53,0xff,0xff,0x24,0x04,0x44,0x41,
   0x59,0x24,0x1f,0x00,0x24,0x04,0x44,0x41,0x59,0x24,0x1c,0x00,0x22,0x00,0x10,0xc0,
   0x81,0x22,0x00,0x03,0x6a,0x0f,0xff,0xe3,0x8c,0x86,0x22,0x00,0x02,0xbc,0x81,0x0f,
   0xff,0xdf,0x9a,0x86,0x22,0x00,0x02,0xbc,0x81,0x0f,0xff,0xd9,0xa1,0x86,0x22,0x00,
   0x04,0xbc,0x81,0x22,0x00,0x01,0x22,0x00,0x02,0x4c,0x0f,0xff,0xe3,0x6b,0x22,0x00,
   0x04,0x22,0x00,0x02,0x4c,0x0f,0xff,0xdf,0x6b,0x22,0x00,0x08,0x22,0x00,0x02,0x4c,
   0x0f,0xff,0xd9,0x6b,0x24,0x01,0x44,0x1e,0x00,0x02,0xff,0xe3,0xb5,0x02,0xff,0xdf,
   0xb5,0x22,0x00,0x64,0x86,0x3e,0x3c,0x02,0xff,0xd9,0xb5,0x22,0x27,0x10,0x86,0x3e,
   0x3c,0x80,0x22,0x00,0x01,0x6a,0x53,0x00,0x00,0x51,0x00,0x24,0x24,0x01,0x44,0x1e,
   0x00,0xa1,0x86,0x80,0x24,0x01,0x44,0x1e,0x00,0x24,0x01,0x44,0x1b,0x00,0x22,0x27,
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
  };
#endif

////////////////////////////////////////////////////////////////////////////////
//
typedef struct {
  FATFS fatfs;
  char const *const name;
} fatfs_dscr_t;

static fatfs_dscr_t fatfs_dscrs[2] = {{.name = "0:"}, {.name = "1:"}};
static FATFS *get_fs_by_name(const char *name) {
  for (size_t i = 0; i < count_of(fatfs_dscrs); ++i) {
    if (0 == strcmp(fatfs_dscrs[i].name, name)) {
      return &fatfs_dscrs[i].fatfs;
    }
  }
  return NULL;

}

static bool logger_enabled;
static const uint32_t period = 1000;
static absolute_time_t next_time;

////////////////////////////////////////////////////////////////////////////////



// I2C Port descriptor
typedef struct _I2C_PORT_DESC
{
  unsigned char sdaport;
  unsigned char sdabit;
  unsigned char sclport;
  unsigned char sclbit;
} I2C_PORT_DESC;

// Slave device descriptor
typedef struct _I2C_SLAVE_DESC
{
  I2C_PORT_DESC *port;             // Port the device is on
  unsigned char slave_7bit_addr;        // SLave address
} I2C_SLAVE_DESC;

// I2C functions
void i2c_release(I2C_PORT_DESC *port);
void i2c_delay(I2C_PORT_DESC *port);
void i2c_sda_low(I2C_PORT_DESC *port);
void i2c_sda_high(I2C_PORT_DESC *port);
void i2c_scl_low(I2C_PORT_DESC *port);
void i2c_scl_high(I2C_PORT_DESC *port);
void i2c_start(I2C_PORT_DESC *port);
void i2c_stop(I2C_PORT_DESC *port);
int i2c_send_byte(I2C_PORT_DESC *port, BYTE b);
int i2c_read_bytes(I2C_SLAVE_DESC *slave, int n, BYTE *data);
void i2c_send_bytes(I2C_SLAVE_DESC *slave, int n, BYTE *data);
#

#endif /* I2C_FUNCTIONS_H_ */
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

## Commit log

2021-08-20 Initial check in
    [pico-rom-emulator-1.kicad_pcb, pico-rom-emulator-1.sch]
2021-08-20 PCB updates
    [pico-rom-emulator-1.sch]
2021-10-23 Added C code for emulator
    [pico-rom-emulator-1.kicad_pcb, pico-rom-emulator-1.sch]
